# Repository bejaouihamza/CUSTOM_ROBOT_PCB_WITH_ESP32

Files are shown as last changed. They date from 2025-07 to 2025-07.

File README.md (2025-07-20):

# CUSTOM_ROBOT_PCB_WITH_ESP32
A custom-designed PCB for robotics applications, featuring the ESP32-C3-WROOM-2 microcontroller with WiFi & Bluetooth connectivity, motor control via the L298P H-bridge, efficient power management, and USB isolation for safe programming.

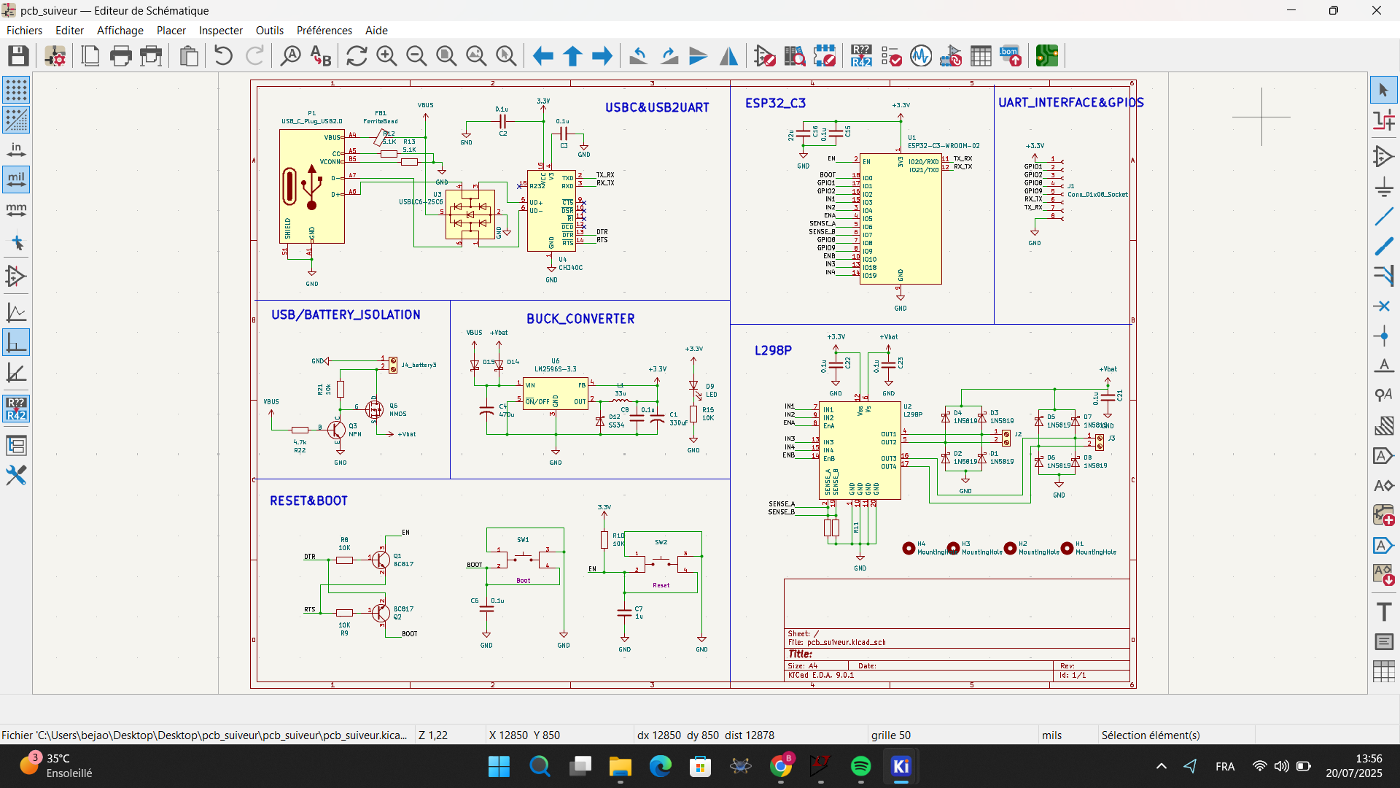
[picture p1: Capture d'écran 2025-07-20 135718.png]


Key Features
🚀 Core Components
ESP32-C3-WROOM-2 – RISC-V-based MCU with WiFi 4 & Bluetooth 5 (BLE)

L298P Motor Driver – Dual H-bridge for controlling two DC motors or one stepper motor

CH340C USB-UART – Reliable serial communication for programming and debugging

USB Battery Isolation – Prevents backpowering issues during programming

12V Battery Input – Supports LiPo/Li-ion batteries with proper protection

⚡ Power Management
Buck Converter (12V → 5V/3.3V) – Efficient voltage regulation for MCU & peripherals

Battery Monitoring – Optional voltage divider for battery level sensing

🔌 Connectivity & I/O
USB-C Port – For programming & serial communication

Bluetooth/WiFi Control – Remote operation via smartphone or PC

GPIO Breakout – Access to unused ESP32 pins for sensors & expansions

🛠️ Applications
Autonomous Robots (Line-following, obstacle avoidance)

RC Vehicles (WiFi/Bluetooth-controlled)

IoT-Enabled Robotics (Telemetry, remote control)

📌 Schematic & Design Files
Designed in KiCad (schematics & PCB layout included)

Gerber files ready for manufacturing
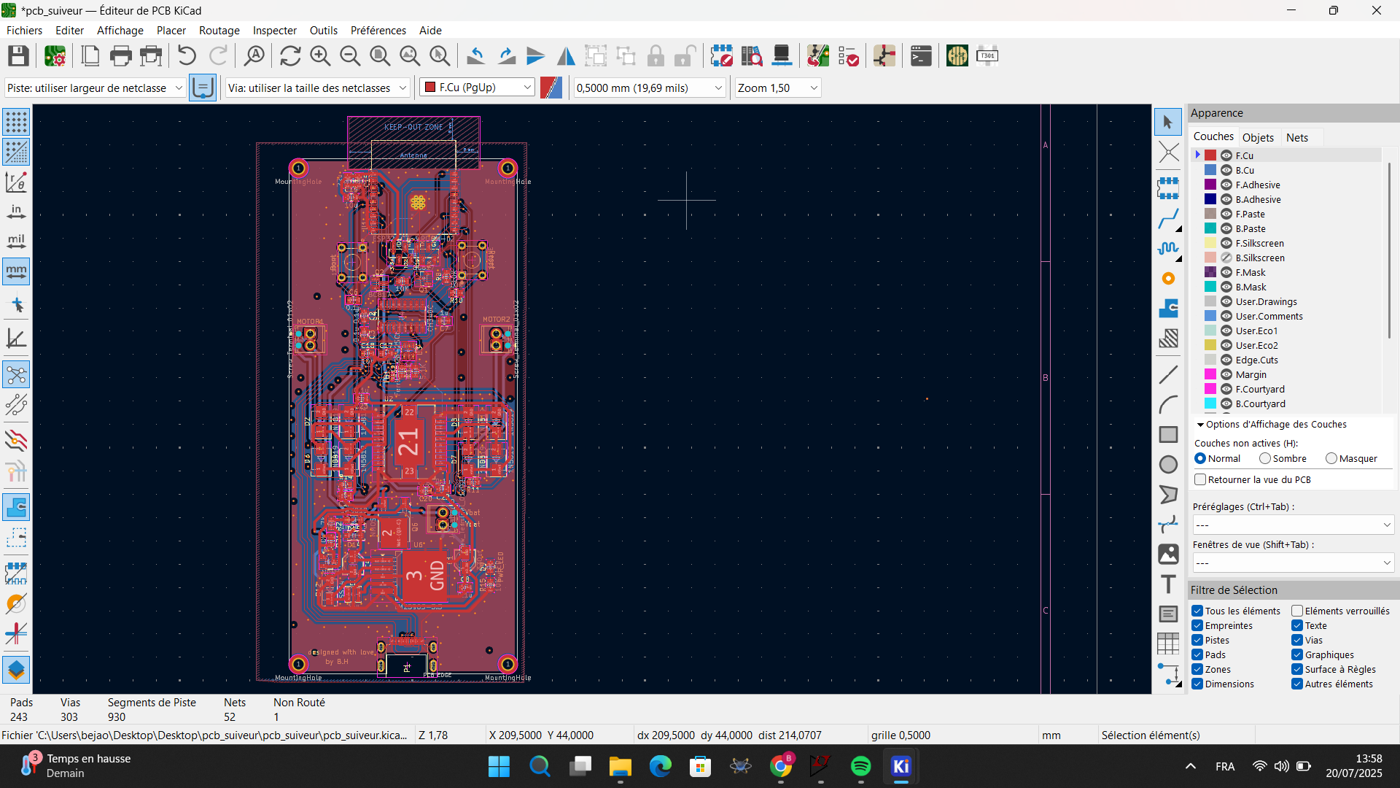
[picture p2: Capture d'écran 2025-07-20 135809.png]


🔧 Getting Started
Flash the ESP32-C3 via USB-C .

Power via 12V battery – The buck converter supplies stable 5V/3.3V to the system.

Control motors via the L298P using PWM signals from the ESP32.

Use WiFi/BLE for wireless communication (Arduino/ESP-IDF supported).

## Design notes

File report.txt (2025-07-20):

Fichier placement côté composant (dessus): 'C:\Users\bejao\Desktop\Desktop\pcb_suiveur\pcb_suiveur\pcb_suiveur-backups\pcb_suiveur-top-pos.csv'.
Info: Nombre de composants: 56.
Fichier placement côté soudure (dessous): 'C:\Users\bejao\Desktop\Desktop\pcb_suiveur\pcb_suiveur\pcb_suiveur-backups\pcb_suiveur-bottom-pos.csv'.
Info: Nombre de composants: 0.
Info: Nombre total de composants: 56.
Info: Fini.

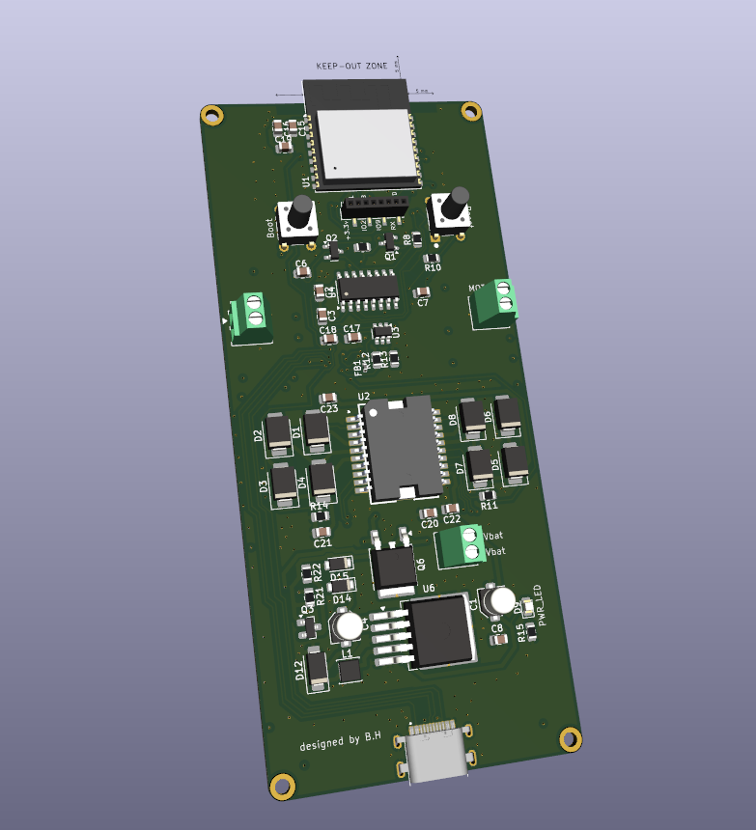
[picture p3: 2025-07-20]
Capture d'écran 2025-07-20 140147.png

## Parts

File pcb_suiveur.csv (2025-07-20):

Reference | Value | Footprint | Datasheet | Qty | DNP | Exclude from BOM | Exclude from Board
C1 | 330uf | Capacitor_SMD:C_Elec_4x5.4 |  | 1
C2,C3,C6,C8,C15,C21,C22,C23 | 0.1u | Capacitor_SMD:C_0805_2012Metric | https://cdn.sparkfun.com/assets/8/a/4/a/5/Kemet_Capacitor_Datasheet.pdf | 8
C4 | 470u | Capacitor_SMD:C_Elec_4x5.4 |  | 1
C7 | 1u | Capacitor_SMD:C_0805_2012Metric | https://cdn.sparkfun.com/assets/8/a/4/a/5/Kemet_Capacitor_Datasheet.pdf | 1
C16 | 22u | Capacitor_SMD:C_0805_2012Metric | https://cdn.sparkfun.com/assets/8/a/4/a/5/Kemet_Capacitor_Datasheet.pdf | 1
D1,D2,D3,D4,D5,D6,D7,D8 | 1N5819 | Diode_SMD:D_SMB | http://www.vishay.com/docs/88525/1n5817.pdf | 8
D9 | LED | LED_SMD:LED_0805_2012Metric | ~ | 1
D12 | SS34 | Diode_SMD:D_SMA | https://www.vishay.com/docs/88751/ss32.pdf | 1
D14,D15 | 1N5819 | Diode_SMD:D_SMF | http://www.vishay.com/docs/88525/1n5817.pdf | 2
FB1 | FerriteBead | Inductor_SMD:L_0402_1005Metric | ~ | 1
H1,H2,H3,H4 | MountingHole | MountingHole:MountingHole_2.2mm_M2_DIN965_Pad_TopOnly | ~ | 4 |  | Exclure de la Liste du Matériel
J1 | Conn_01x08_Socket | Connector_PinSocket_1.27mm:PinSocket_1x08_P1.27mm_Vertical_SMD_Pin1Right | ~ | 1
J2,J3,J4_battery3 | Screw_Terminal_01x02 | TerminalBlock_Phoenix:TerminalBlock_Phoenix_MPT-0,5-2-2.54_1x02_P2.54mm_Horizontal | ~ | 3
L1 | 33u | Inductor_SMD:L_APV_ANR3010 | ~ | 1
P1 | USB_C_Plug_USB2.0 | New_Library:TE_2340901-1 | https://www.usb.org/sites/default/files/documents/usb_type-c.zip | 1
Q1,Q2 | BC817 | Package_TO_SOT_SMD:SOT-23 | https://www.onsemi.com/pub/Collateral/BC818-D.pdf | 2
Q3 | NPN | Package_TO_SOT_SMD:SuperSOT-3 | https://ngspice.sourceforge.io/docs/ngspice-html-manual/manual.xhtml#cha_BJTs | 1
Q6 | NMOS | Package_TO_SOT_SMD:TO-252-2 | https://ngspice.sourceforge.io/docs/ngspice-html-manual/manual.xhtml#cha_MOSFETs | 1
R8,R9,R10,R15 | 10K | Resistor_SMD:R_0805_2012Metric | ~ | 4
R11,R14 | 1 | Resistor_SMD:R_0805_2012Metric | ~ | 2
R12,R13 | 5.1K | Resistor_SMD:R_0805_2012Metric | ~ | 2
R21 | 10k | Resistor_SMD:R_0805_2012Metric | ~ | 1
R22 | 4.7k | Resistor_SMD:R_0805_2012Metric | ~ | 1
SW1,SW2 | 1101NE | New_Library:SW_FSM8JH | https://www.sparkfun.com/datasheets/Components/1101.pdf | 2
U1 | ESP32-C3-WROOM-02 | RF_Module:ESP32-C3-WROOM-02 | https://www.espressif.com/sites/default/files/documentation/esp32-c3-wroom-02_datasheet_en.pdf | 1
U2 | L298P | New_Library:SOIC127P1420X360-20N | http://www.st.com/st-web-ui/static/active/en/resource/technical/document/datasheet/CD00000240.pdf | 1
U3 | USBLC6-2SC6 | Package_TO_SOT_SMD:SOT-23-6 | https://www.st.com/resource/en/datasheet/usblc6-2.pdf | 1
U4 | CH340C | Package_SO:SOIC-16_3.9x9.9mm_P1.27mm | https://datasheet.lcsc.com/szlcsc/Jiangsu-Qin-Heng-CH340C_C84681.pdf | 1
U6 | LM2596S-3.3 | Package_TO_SOT_SMD:TO-263-5_TabPin3 | http://www.ti.com/lit/ds/symlink/lm2596.pdf | 1

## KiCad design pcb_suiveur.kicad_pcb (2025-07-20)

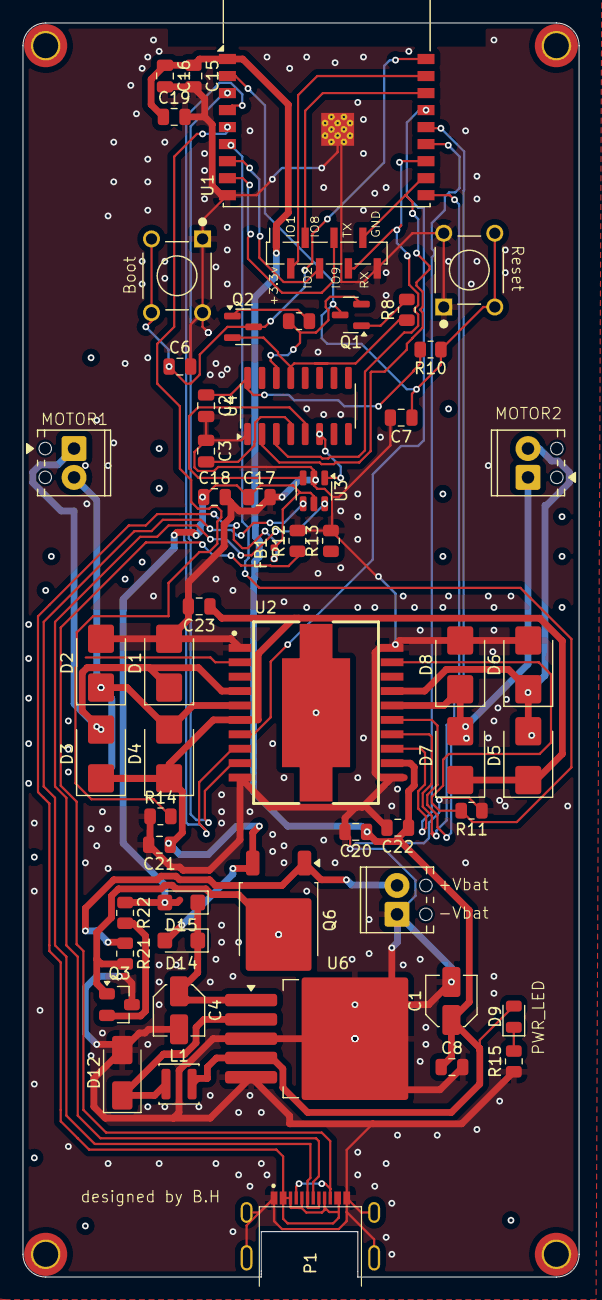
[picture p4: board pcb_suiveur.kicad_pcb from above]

Board: 2 copper layers, 49.0 x 110.5 mm, 60 parts (0 on the bottom side), 42 nets.

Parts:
C1: 330uf; C_Elec_4x5.4
C2, C3, C6, C8, C15, C20, C21, C22, C23: 0.1u; C_0805_2012Metric
C4: 470u; C_Elec_4x5.4
C7, C17: 1u; C_0805_2012Metric
C16: 22u; C_0805_2012Metric
C18, C19: 10u; C_0805_2012Metric
D1, D2, D3, D4, D5, D6, D7, D8: 1N5819; D_SMB
D9: LED; LED_0805_2012Metric
D12: SS34; D_SMA
D14, D15: 1N5819; D_SMF
FB1: FerriteBead; L_0402_1005Metric
H1, H2, H3, H4: MountingHole; MountingHole_2.2mm_M2_DIN965_Pad_TopOnly
J1: Conn_01x08_Socket; PinSocket_1x08_P1.27mm_Vertical_SMD_Pin1Right
J2, J3, J4_battery3: Screw_Terminal_01x02; TerminalBlock_Phoenix_MPT-0,5-2-2.54_1x02_P2.54mm_Horizontal
L1: 33u; L_APV_ANR3010
P1: USB_C_Plug_USB2.0; TE_2340901-1
Q1, Q2: BC817; SOT-23
Q3: NPN; SuperSOT-3
Q6: NMOS; TO-252-2
R8, R9, R10, R15: 10K; R_0805_2012Metric
R11, R14: 1; R_0805_2012Metric
R12, R13: 5.1K; R_0805_2012Metric
R21: 10k; R_0805_2012Metric
R22: 4.7k; R_0805_2012Metric
SW1, SW2: 1101NE; SW_FSM8JH
U1: ESP32-C3-WROOM-02
U2: L298P; SOIC127P1420X360-20N
U3: USBLC6-2SC6; SOT-23-6
U4: CH340C; SOIC-16_3.9x9.9mm_P1.27mm
U6: LM2596S-3.3; TO-263-5_TabPin3

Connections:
3.3V: C2.1, R10.2, U4.16 (VCC)
+3.3V: C1.1, C8.1, C15.1, C16.1, C19.1, C20.1, C22.1, D9.2 (A), J1.1, L1.2, U1.1 (3V3), U2.12 (Vss), U6.4 (FB)
+Vbat: C21.1, C23.1, D3.1 (K), D4.1 (K), D5.1 (K), D7.1 (K), D14.2 (A), Q6.3 (S), U2.6 (Vs)
/BOOT: C6.1, Q2.3 (C), SW1.2, SW1.4, U1.18 (IO0)
/DTR: Q2.2 (E), R8.1, U4.13 (~DTR)
/EN: C7.1, Q1.3 (C), R10.1, SW2.2, SW2.4, U1.2 (EN)
/ENA: U1.4 (IO5), U2.8 (EnA)
/ENB: U1.10 (IO10), U2.14 (EnB)
/GPIO1: J1.2, U1.17 (IO1)
/GPIO2: J1.3, U1.16 (IO2)
/GPIO8: J1.4, U1.7 (IO8)
/GPIO9: J1.5, U1.8 (IO9)
/IN1: U1.15 (IO3), U2.7 (IN1)
/IN2: U1.3 (IO4), U2.9 (IN2)
/IN3: U1.13 (IO18), U2.13 (IN3)
/IN4: U1.14 (IO19), U2.15 (IN4)
/RTS: Q1.2 (E), R9.1, U4.14 (~RTS)
/RX_TX: J1.6, U1.12 (IO21/TXD), U4.3 (RXD)
/SENSE_A: R14.2, U1.5 (IO6), U2.2 (SENSE_A)
/SENSE_B: R11.2, U1.6 (IO7), U2.19 (SENSE_B)
/TX_RX: J1.7, U1.11 (IO20/RXD), U4.2 (TXD)
GND: C1.2, C2.2, C3.1, C4.2, C6.2, C7.2, C8.2, C15.2, C16.2, C17.2, C18.2, C19.2, C20.2, C21.2, C22.2, C23.2, D1.2 (A), D2.2 (A), D6.2 (A), D8.2 (A), D12.2 (A), J1.8, J4_battery3.1, P1.A1 (GND), Q3.3 (E), R11.1, R12.2, R13.2, R14.1, R15.1, SW1.1, SW1.3, SW2.1, SW2.3, U1.9 (GND), U1.19 (GND), U2.1 (GND), U2.10 (GND), U2.11 (GND), U2.20 (GND), U3.2 (GND), U4.1 (GND), U6.3 (GND), U6.5 (~ON/OFF)
unnamed: D1.1 (K), D3.2 (A), J2.1, U2.4 (OUT1)
unnamed: D2.1 (K), D4.2 (A), J2.2, U2.5 (OUT2)
unnamed: D5.2 (A), D6.1 (K), J3.2, U2.17 (OUT4)
unnamed: D7.2 (A), D8.1 (K), J3.1, U2.16 (OUT3)
unnamed: D9.1 (K), R15.2
unnamed: D12.1 (K), L1.1, U6.2 (OUT)
unnamed: C4.1, D14.1 (K), D15.1 (K), U6.1 (VIN)
unnamed: FB1.1, P1.A9 (VBUS)
unnamed: J4_battery3.2, Q6.1 (D), R21.1
unnamed: P1.A5 (CC), R12.1
unnamed: P1.A6 (D+), U3.4 (I/O2)
unnamed: P1.A7 (D-), U3.6 (I/O1)
unnamed: Q1.1 (B), R8.2
unnamed: Q2.1 (B), R9.2
unnamed: Q3.2 (B), R22.2
unnamed: Q3.1 (C), Q6.2 (G), R21.2
unnamed: U3.3 (I/O2), U4.5 (UD+)
unnamed: U3.1 (I/O1), U4.6 (UD-)
unnamed: C3.2, U4.4 (V3)
VBUS: C17.1, C18.1, D15.2 (A), FB1.2, R22.1, U3.5 (VBUS)
